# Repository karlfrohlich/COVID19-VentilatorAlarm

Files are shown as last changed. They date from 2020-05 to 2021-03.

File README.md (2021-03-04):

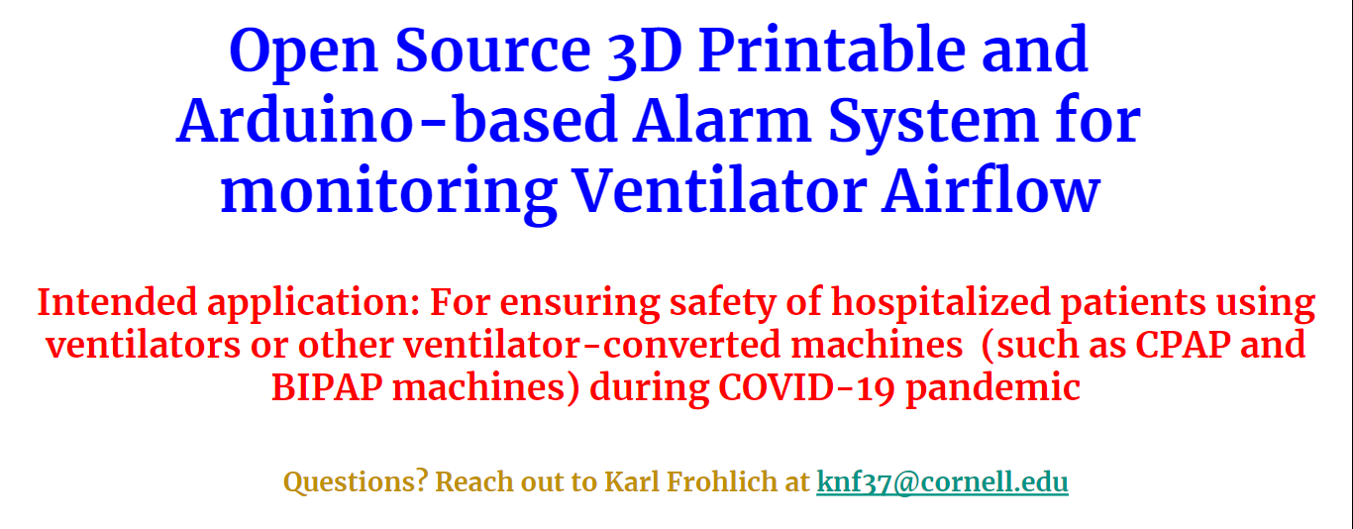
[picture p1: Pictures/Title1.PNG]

________________________________________________________________________________________________________________________________

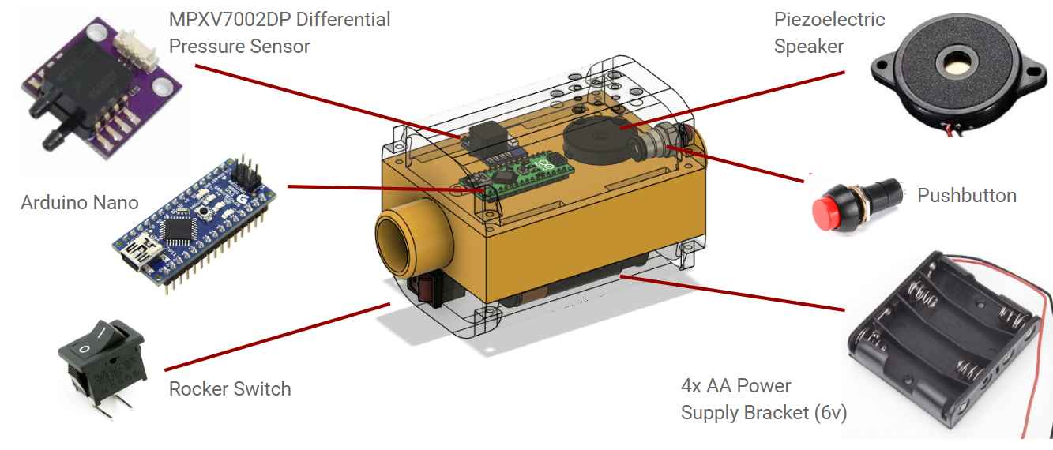
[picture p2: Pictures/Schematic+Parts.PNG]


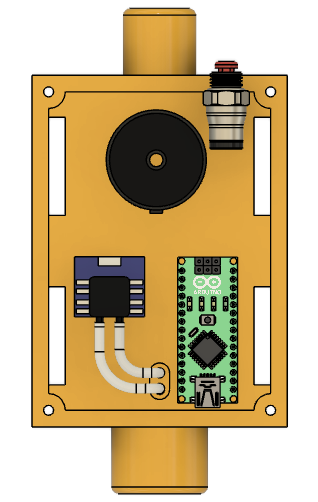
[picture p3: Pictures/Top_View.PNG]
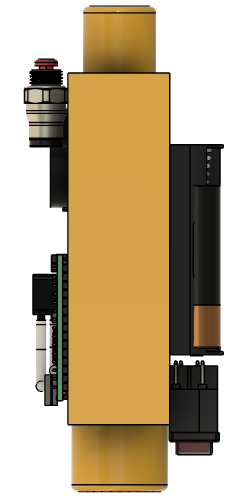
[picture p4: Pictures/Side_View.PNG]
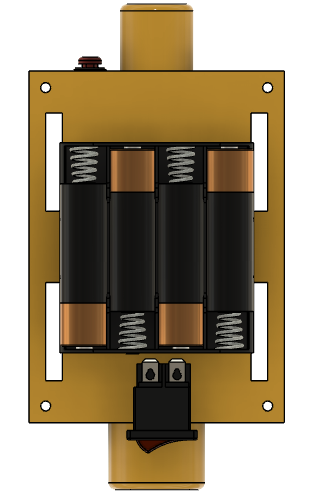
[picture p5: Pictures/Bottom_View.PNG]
 

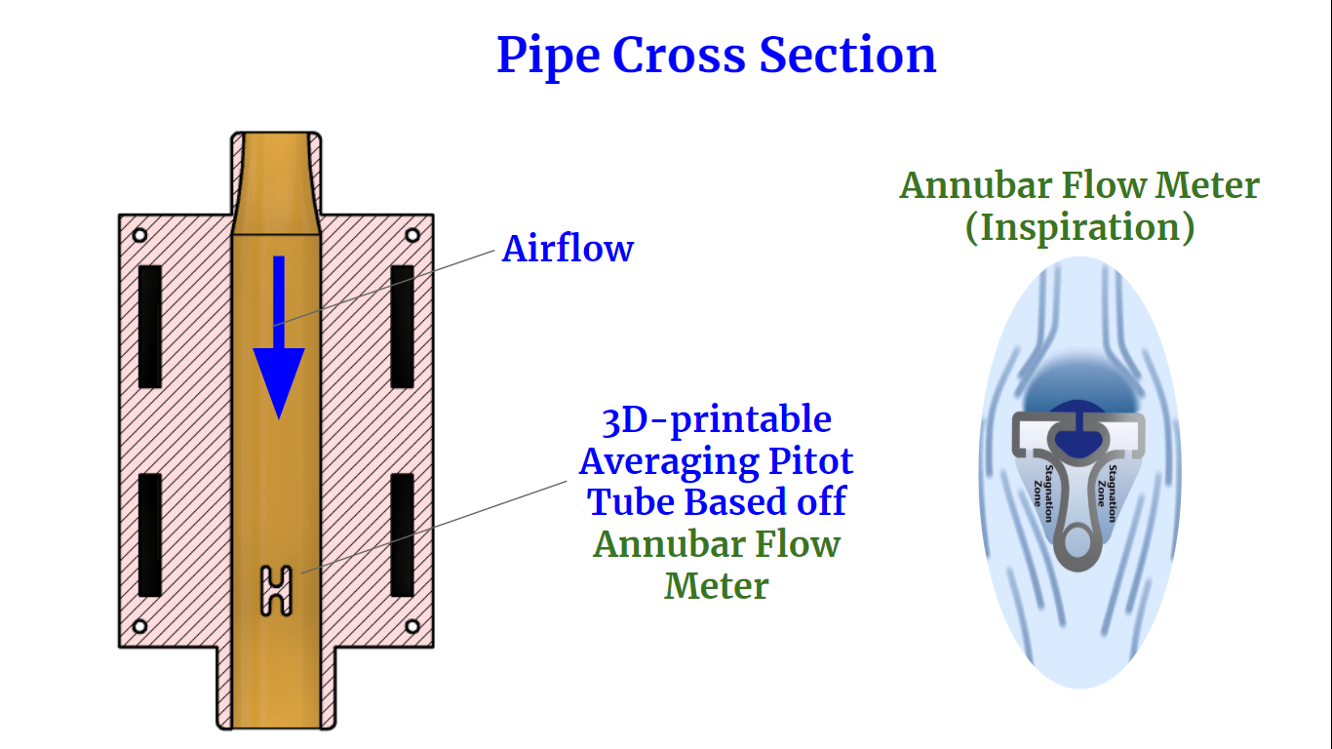
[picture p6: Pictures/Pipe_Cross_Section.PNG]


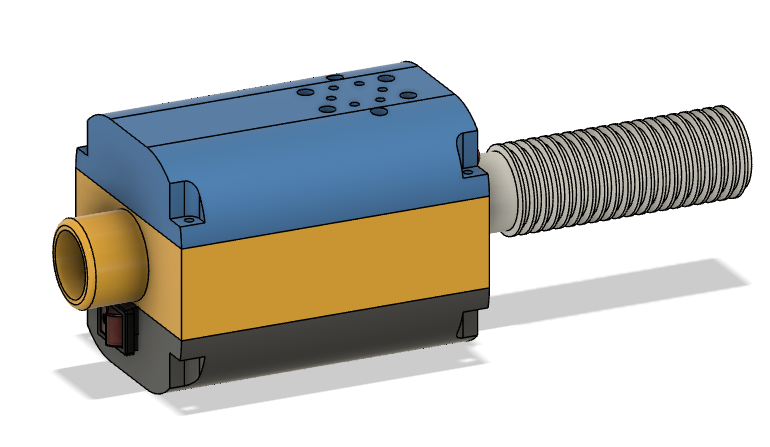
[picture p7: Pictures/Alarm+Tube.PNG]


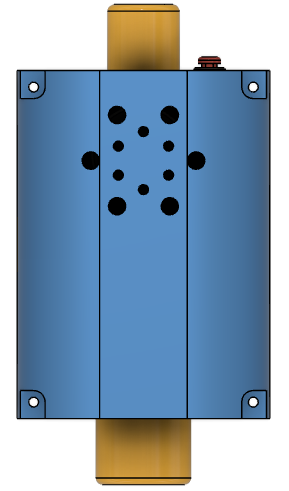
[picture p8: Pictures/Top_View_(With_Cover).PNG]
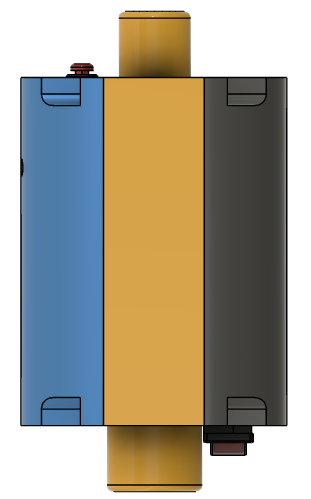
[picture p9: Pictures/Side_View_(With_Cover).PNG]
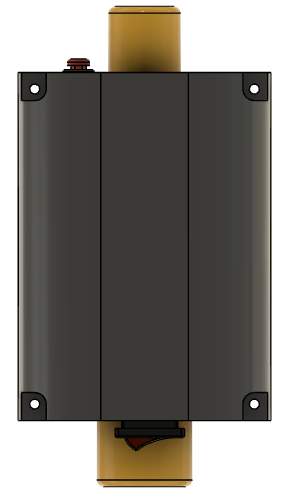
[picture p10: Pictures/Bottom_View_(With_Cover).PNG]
   

# Code Simulated Using Autodesk Tinkercad (See Code folder)
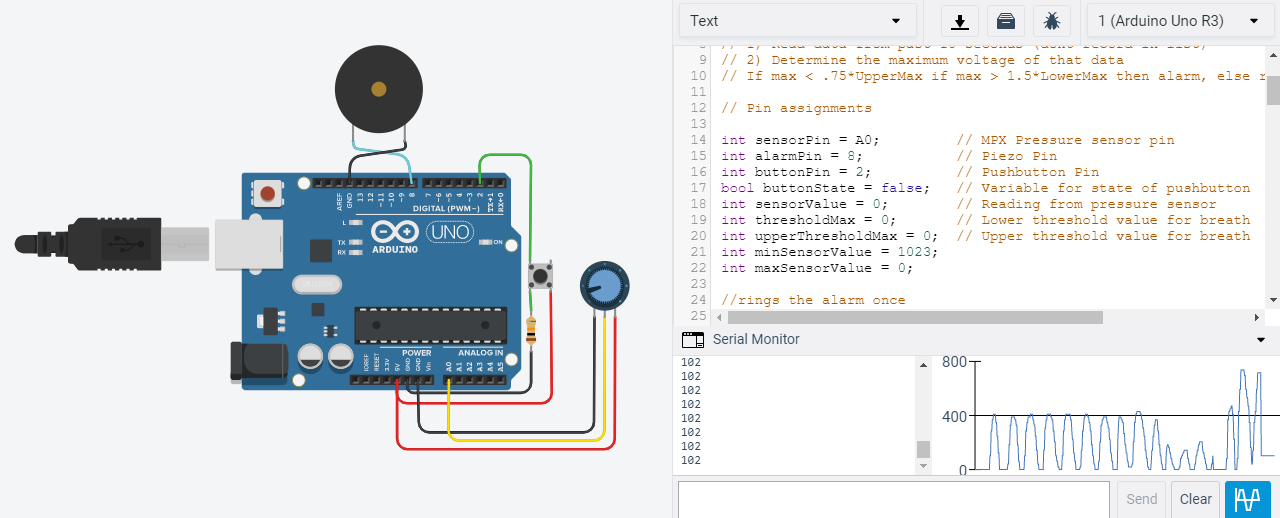
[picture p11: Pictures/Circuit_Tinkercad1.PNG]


## How to Make the Alarm System:
### 1) Purchase all electronic components listed in the Required_Parts Folder
### 2) Download .STL files from the 3D_Printed_Parts Folder
### 3) 3D Print the files (we recommend using PLA plastic at >50% infill)
### 4) Assemble the plastic and electric parts to specification as seen in the Pictures Folder
### 5) Download the code from the Arduino_Code Folder and upload it to the Arduino Board

### 6) Contact me at knf37@cornell.edu for any questions

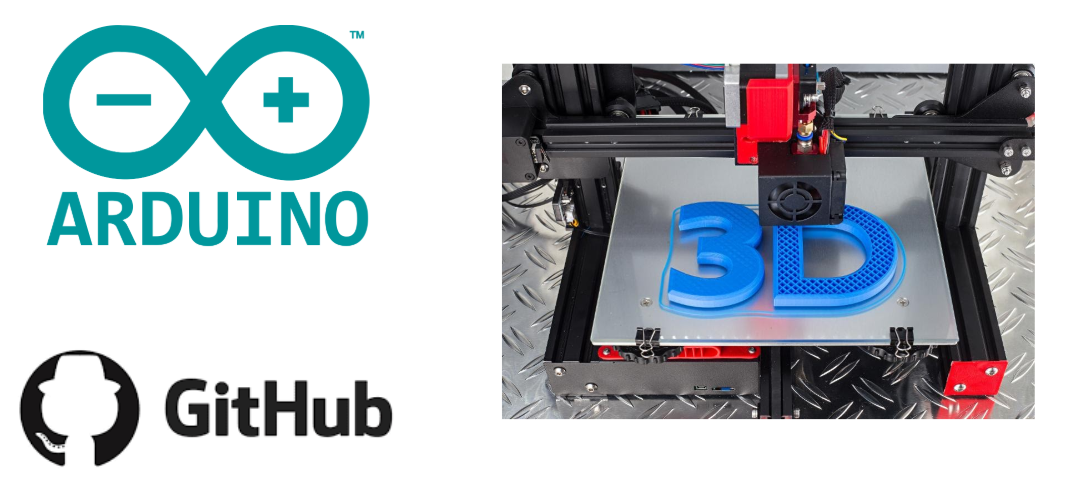
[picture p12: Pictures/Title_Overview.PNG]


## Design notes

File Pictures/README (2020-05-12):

Final Presentation File includes all slides presented on 5/12/2020 for for the Cornell Spring 2020 Class titled "Bioinstrumentation". Course code: BEE 4500

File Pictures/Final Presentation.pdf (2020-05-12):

# An Open Source 3D Printable and Arduino-based Alarm System for monitoring Ventilator Airflow

# Dr. Alex Maag’s Capstone Design Group:

# - Karl Frohlich

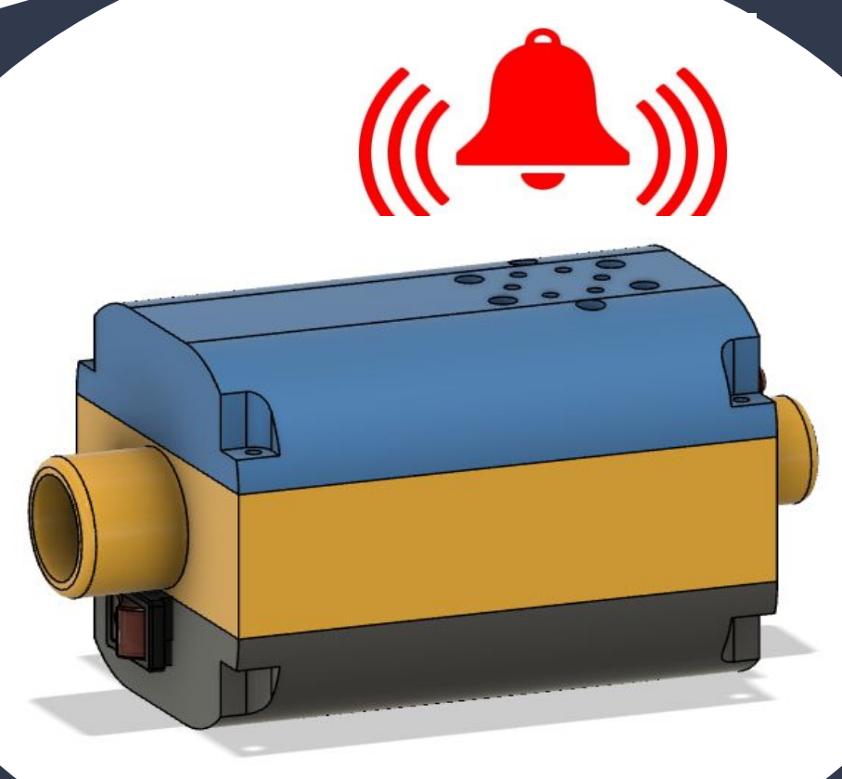
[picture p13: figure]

# - Ian McNitt

# - Noah Marinaro

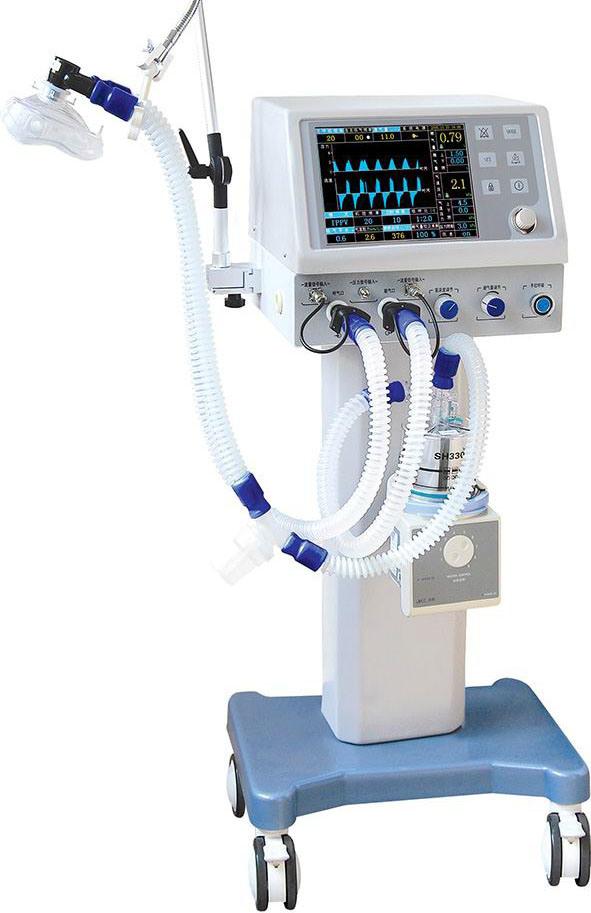
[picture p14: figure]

# Background

## Patient demand of medical equipment during the COVID-19 Pandemic has crippled the supply:

## - Limited to no access to available ventilators - Italy, Spain and NYC are experiencing drastic shortages along with rural hospitals - On March 22, the FDA fast tracked converting sleep apnea machines to ventilators to meet demand - CPAP - BIPAP

# Auburn’s RE-INVENT Project

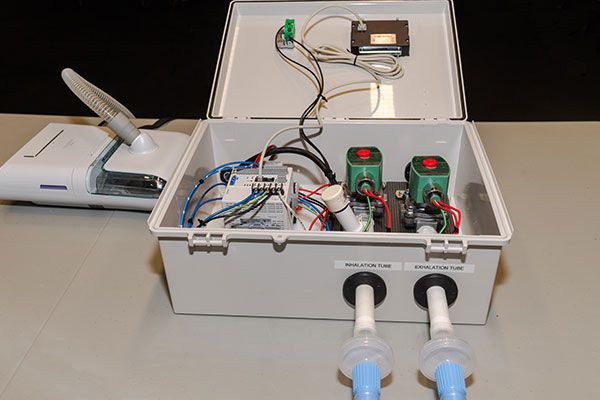
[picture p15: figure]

### Auburn University successfully re-purposed a standard CPAP machine into a functional emergency ventilator:

### - Cost approximately $700 worth of off-the-shelf components - Inspiration to expiration ratio: 1:3 - 3:1 - Breaths per minute: 10 - 30 BPM - Air pressure set: 5 - 25 cmH2O - Alarm senses deviations from patient parameters

# Problems:

## - Aggressive development

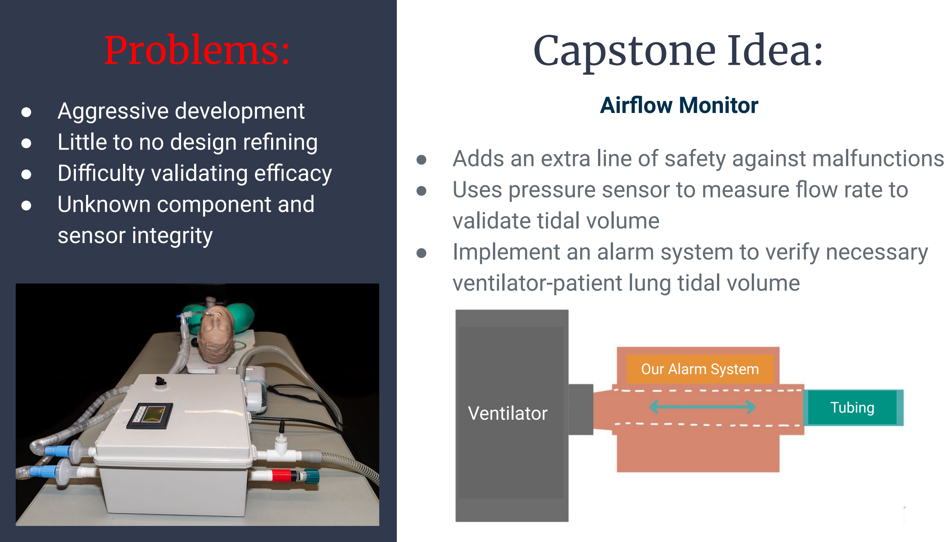
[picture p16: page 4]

## - Little to no design refining - Difficulty validating efficacy - Unknown component and sensor integrity

# Capstone Idea:

## Airflow Monitor

## - Adds an extra line of safety against malfunctions - Uses pressure sensor to measure flow rate to validate tidal volume - Implement an alarm system to verify necessary ventilator-patient lung tidal volume

### Ventilator

Our Alarm System

Tubing

# How Mechanical Ventilation Works

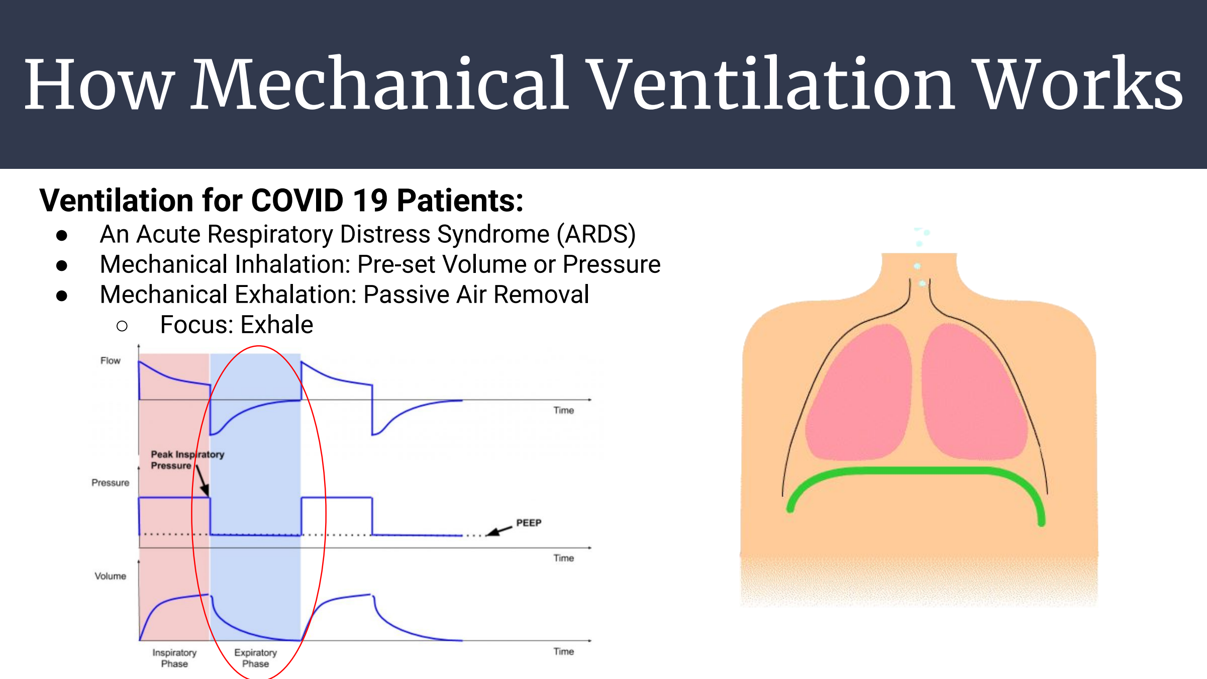
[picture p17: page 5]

# Ventilation for COVID 19 Patients:

## - An Acute Respiratory Distress Syndrome (ARDS) - Mechanical Inhalation: Pre-set Volume or Pressure - Mechanical Exhalation: Passive Air Removal - Focus: Exhale

# Ventilator Basics

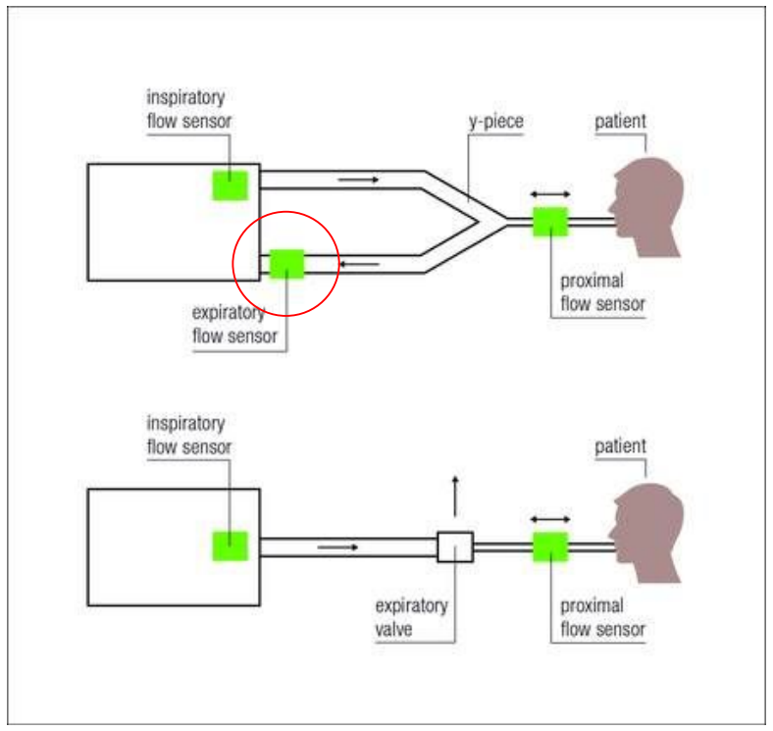
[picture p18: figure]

## 1. Tidal Volume a. The volume of air the lungs will receive b. Set by a medical professional c. What we will be measuring

## 2. Inspiratory Phase (‘Triggering’) a. Inside the ventilator

## 3. Expiratory Phase (‘Cycling’) a. Our emphasis b. Outside the ventilator c. Difficult to tamper with

# Using a Pitot Tube to Measure Flow Rate

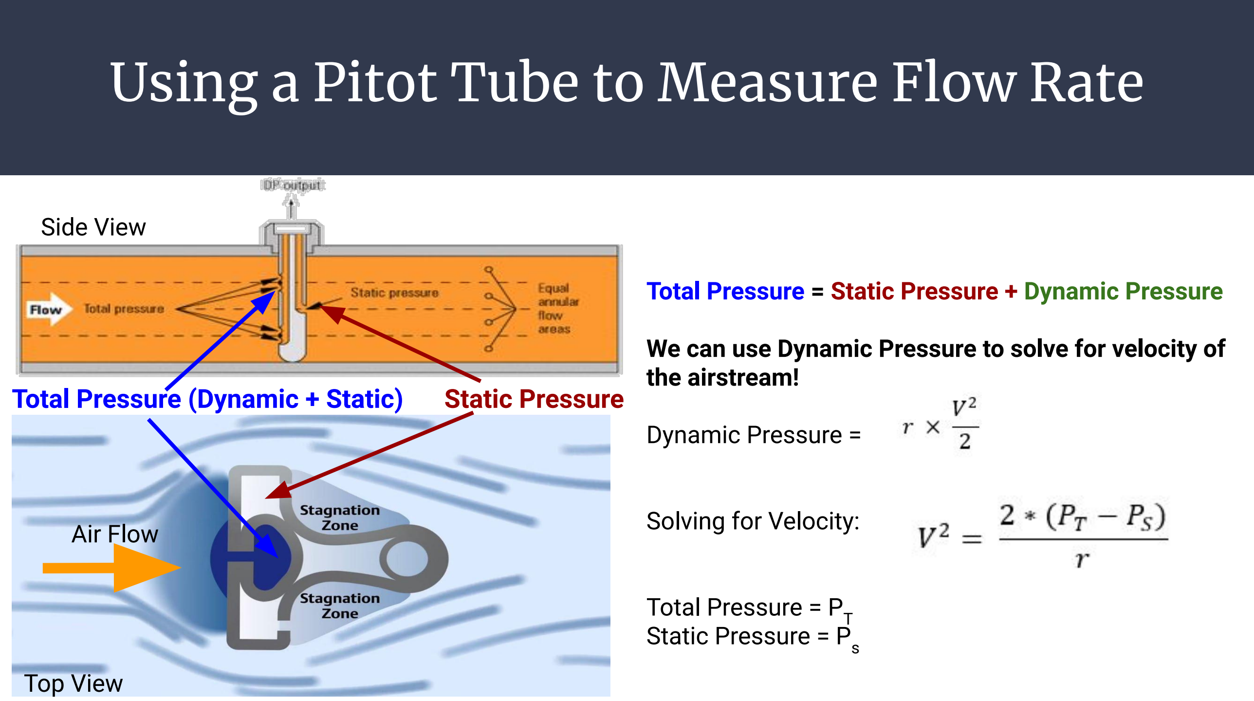
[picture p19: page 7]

## Total Pressure (Dynamic + Static) Static Pressure

### Total Pressure = Static Pressure + Dynamic Pressure

### We can use Dynamic Pressure to solve for velocity of the airstream!

### Dynamic Pressure =

### Solving for Velocity:

### Total Pressure = PT Static Pressure = P

s

### Air Flow

### Side View

### Top View

# An Open Source 3D Printable and Arduino-based Alarm System for monitoring Ventilator Airflow

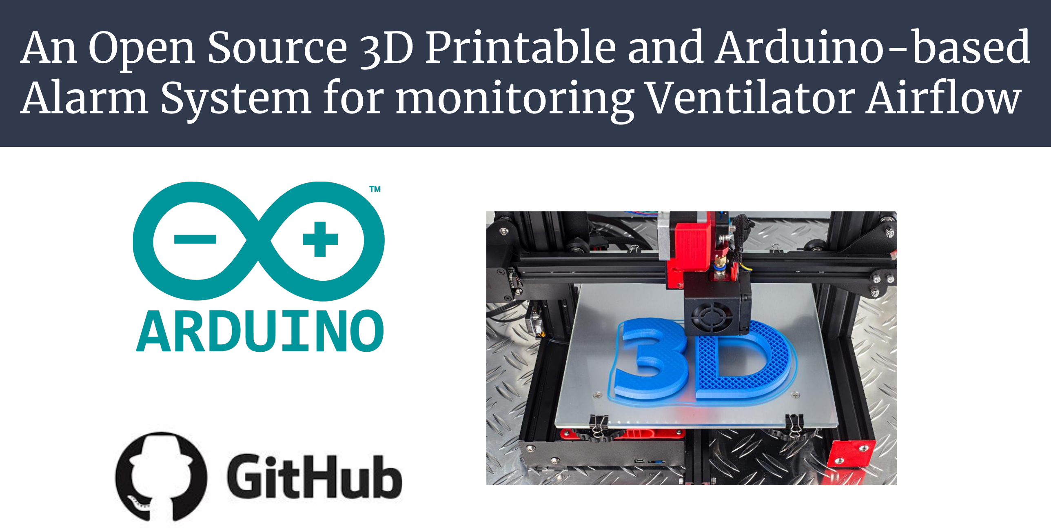
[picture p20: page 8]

# Hardware Overview

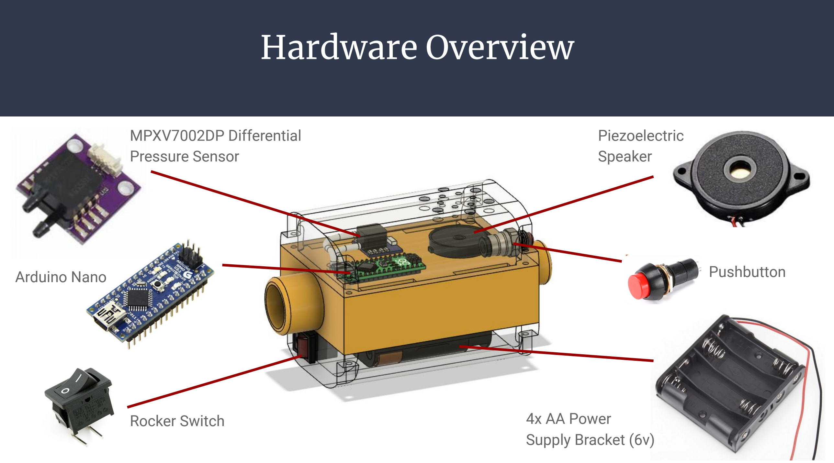
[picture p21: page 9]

### MPXV7002DP Differential Pressure Sensor

### 4x AA Power Supply Bracket (6v)

### Piezoelectric Speaker

### Pushbutton Arduino Nano

### Rocker Switch

# Parts Required

Picture | Part | Price (approx) as of May 2020
| | | Arduino Nano | $7

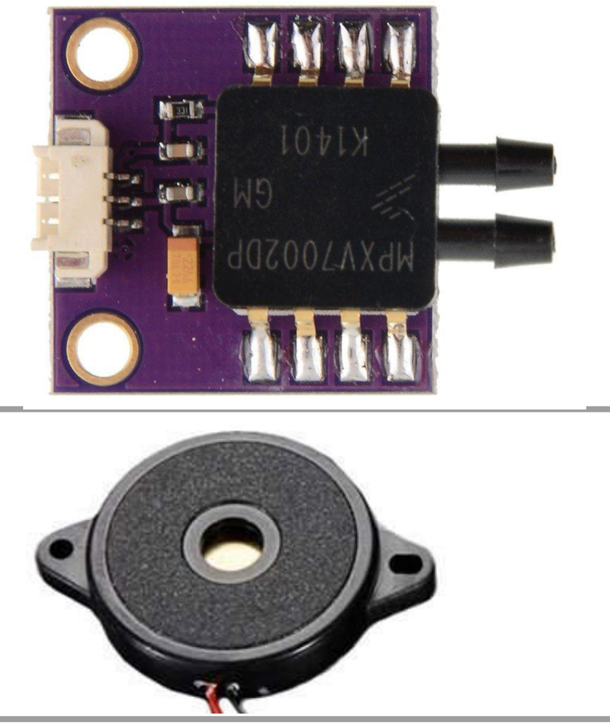
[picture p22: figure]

| | | MPXV7002DP Differential Pressure Sensor | $16
| | | Piezoelectric Speaker | $1
| | | | | 4x AA Power Supply (6V) + 4 AA Batteries | $5
| | | | | | | Pushbutton + Rocker Switch + Resistor + Wires + Screws + 3mm diameter rubber pipe
$11 | Total = $40/unit

# Procedure

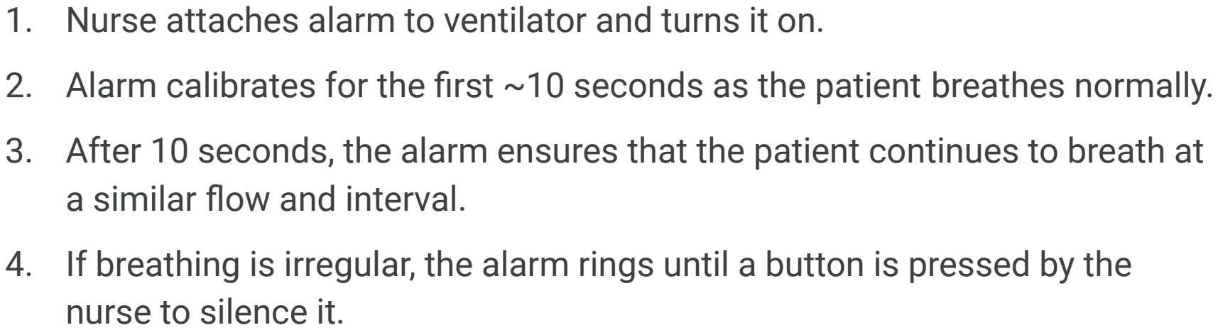
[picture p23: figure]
a similar flow and interval.; nurse to silence it.

1. Nurse attaches alarm to ventilator and turns it on.
2. Alarm calibrates for the first ~10 seconds as the patient breathes normally.

# 3. After 10 seconds, the alarm ensures that the patient continues to breath at

# 4. If breathing is irregular, the alarm rings until a button is pressed by the

# Software/Circuit Overview

# Modeled and Simulated using Autodesk Tinkercad!

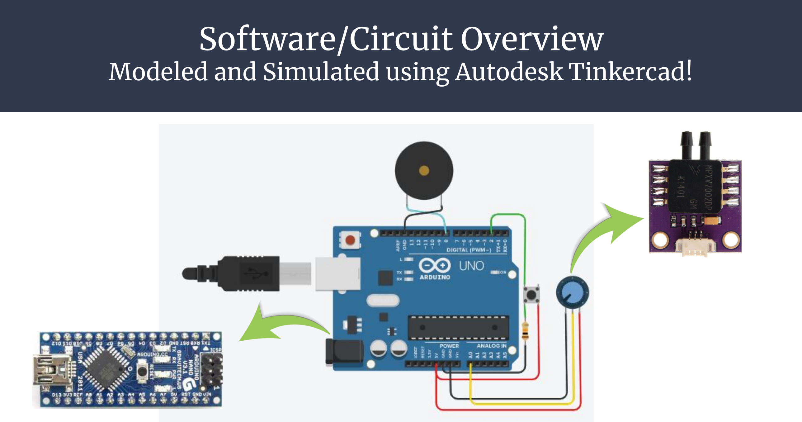
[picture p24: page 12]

# How do you build our Alarm System? Visit our Public Github Repository!

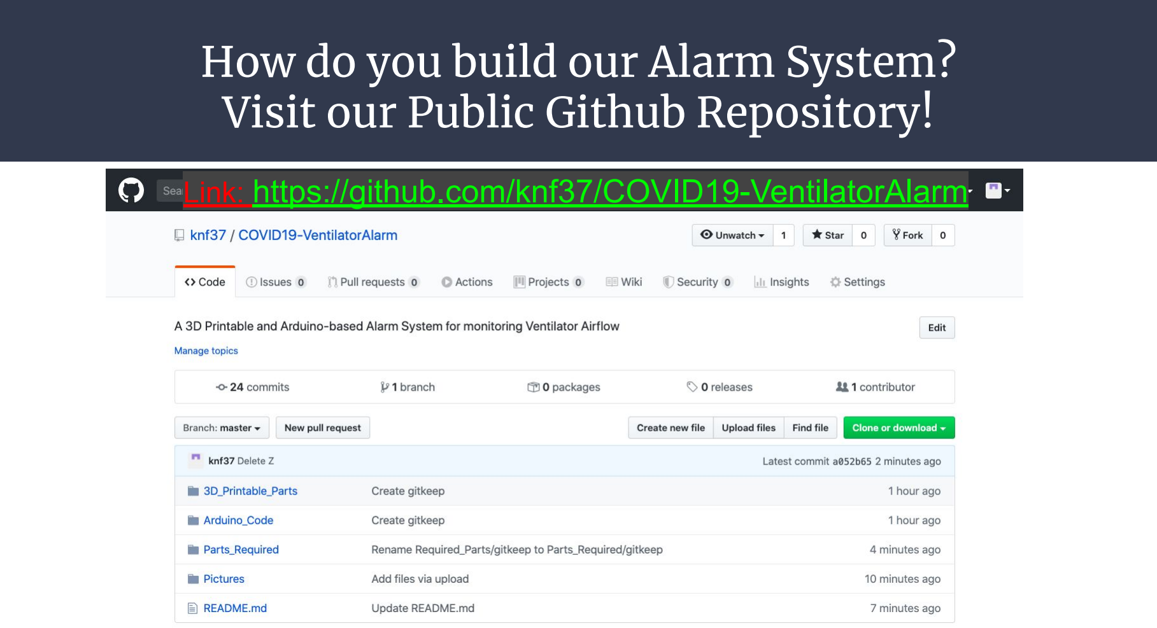
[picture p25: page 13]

# Link: https://github.com/knf37/COVID19-VentilatorAlarm

# Future Direction

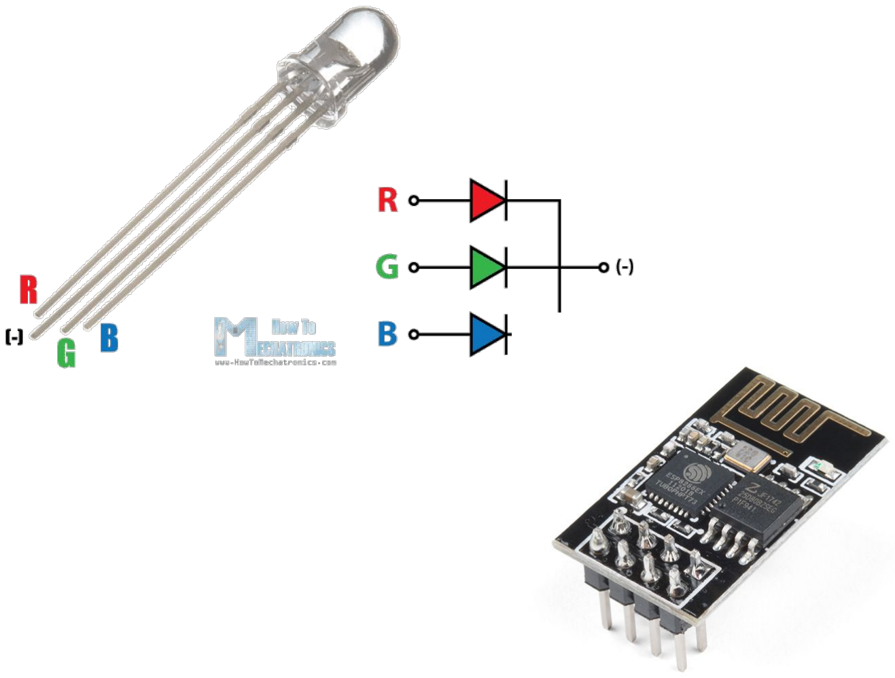
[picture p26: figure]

## - Improve alarm system with LED light - Green = Normal - Yellow = Warning - Red = Needs Attention

## - Transmitter (ESP8266) - Inexpensive ($7) - 24 / 7 monitor capability - Enhanced safety

# Additional Components

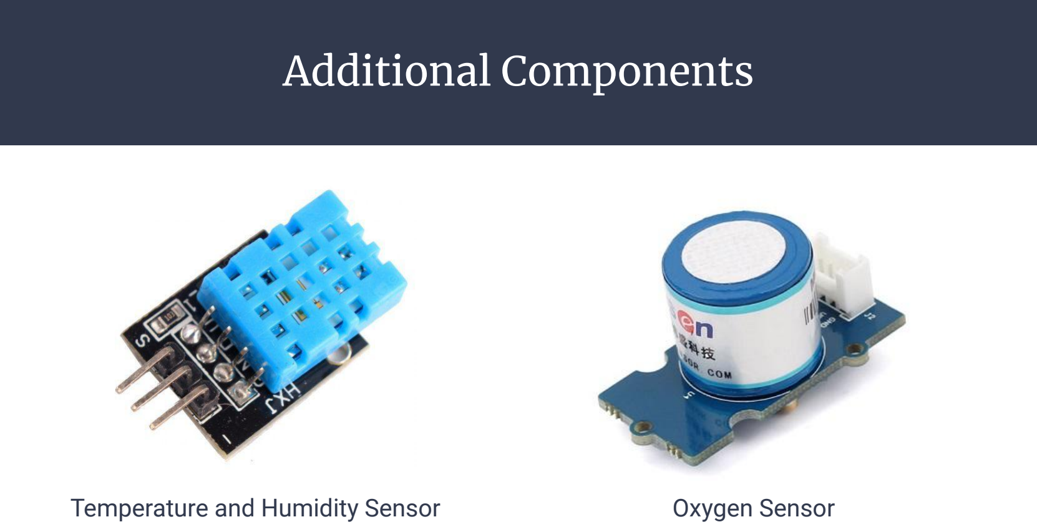
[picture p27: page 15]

Temperature and Humidity Sensor | Oxygen Sensor

# Future Aim

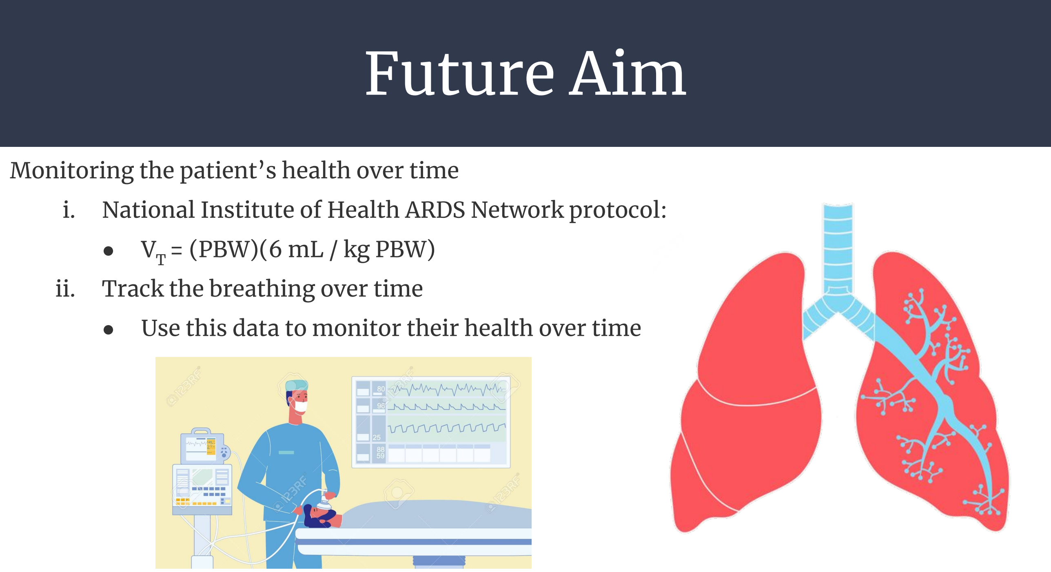
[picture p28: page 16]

# Monitoring the patient’s health over time i. National Institute of Health ARDS Network protocol: - VT = (PBW)(6 mL / kg PBW) ii. Track the breathing over time - Use this data to monitor their health over time

# References

Average Height By State 2020. (2020, April 6). Retrieved May 8, 2020, from https://worldpopulationreview.com/states/average-height-by-state/

Benson, T. Pitot Tube. Retrieved May 8, 2020, from https://www.grc.nasa.gov/WWW/k-12/VirtualAero/BottleRocket/airplane/pitot.html

Burch, T., & Zabala, M. THE AUBURN RE-INVENT PROJECT. Retrieved May 7, 2020, from http://eng.auburn.edu/reinvent

Khoury-Folkens, C. VENTILATOR SOS. Retrieved May 7, 2020, from https://www.ventilatorsos.com/

Mechanical Ventilation. (2016, July). Retrieved May 8, 2020, from https://craighospital.org/resources/mechanical-ventilation

Miller, S., & Wysocki, M. Tidal volumes for ventilated patients should be determined at the endotracheal tube. Retrieved May 7, 2020, from https://www.hamilton-medical.com/dam/jcr:abe1ac16-8732-4bcd-a209-7c5faa076aa8/flow-sns-position_whitepaper-en-689217.00.pdf

Silva, P. L., & Rocco, P. (2018). The basics of respiratory mechanics: ventilator-derived parameters. Annals of translational medicine, 6(19), 376. https://doi.org/10.21037/atm.2018.06.06

Pressure Measuring - MIT E-Vent: MIT Emergency Ventilator. (2020, April 4). Retrieved May 8, 2020, from https://e-vent.mit.edu/controls/pressure-measuring/

# Questions?

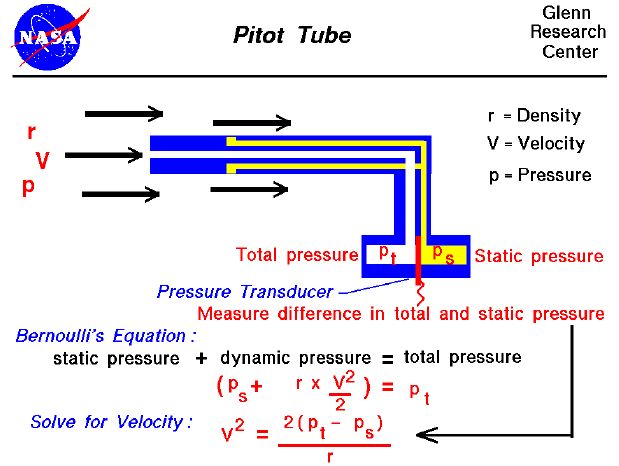
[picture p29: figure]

## Determining the Tidal Volume:

## Q = Flow Rate (m³

/s)

## V = Volume (m³

)

## A = Area (m²

)

## d = distance (m) v = Velocity (m/s) t = Time (s)

## Q = V / t = A*d / t = A*v

## Tidal Volume (VT

) = Q*t

# Measuring Additional Parameters

## - Positive End Expiratory Pressure (PEEP) - Low PEEP: 3 - 5 cmH2O - High PEEP: 12+ cmH2O

## - Peak Inspiratory Pressure (PIP) - Low PIP < 30 cm H2O - High PIP > 40 cm H2O

## - Driving Pressure: PIP - PEEP < 15

# Potential Pressure Readings:

## - Target PEEP: 15 cmH2O - Target PIP: 30 cmH2O - With an I/E ratio of 2:1 and target PEEP: - Male = 424 mL / Female = 317 mL

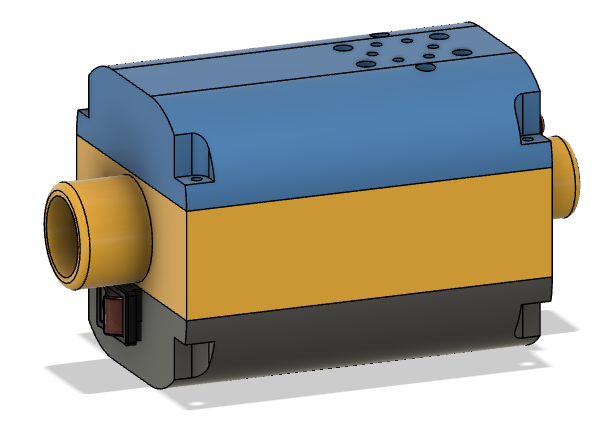
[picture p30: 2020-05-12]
Pictures/Schematic.PNG

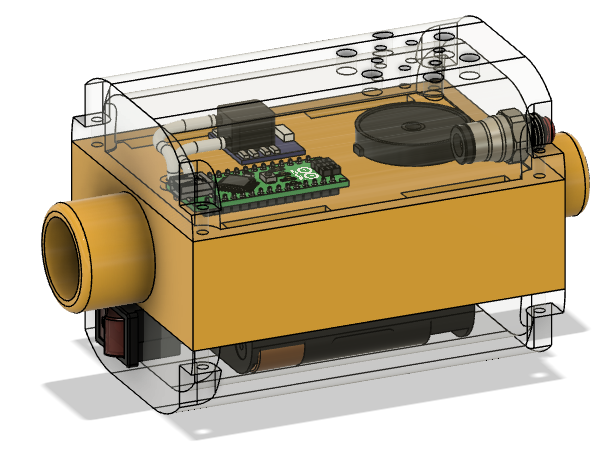
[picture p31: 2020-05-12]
Pictures/Skeleton.PNG

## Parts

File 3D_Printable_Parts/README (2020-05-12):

See full 3d model for the original Fusion 360 file

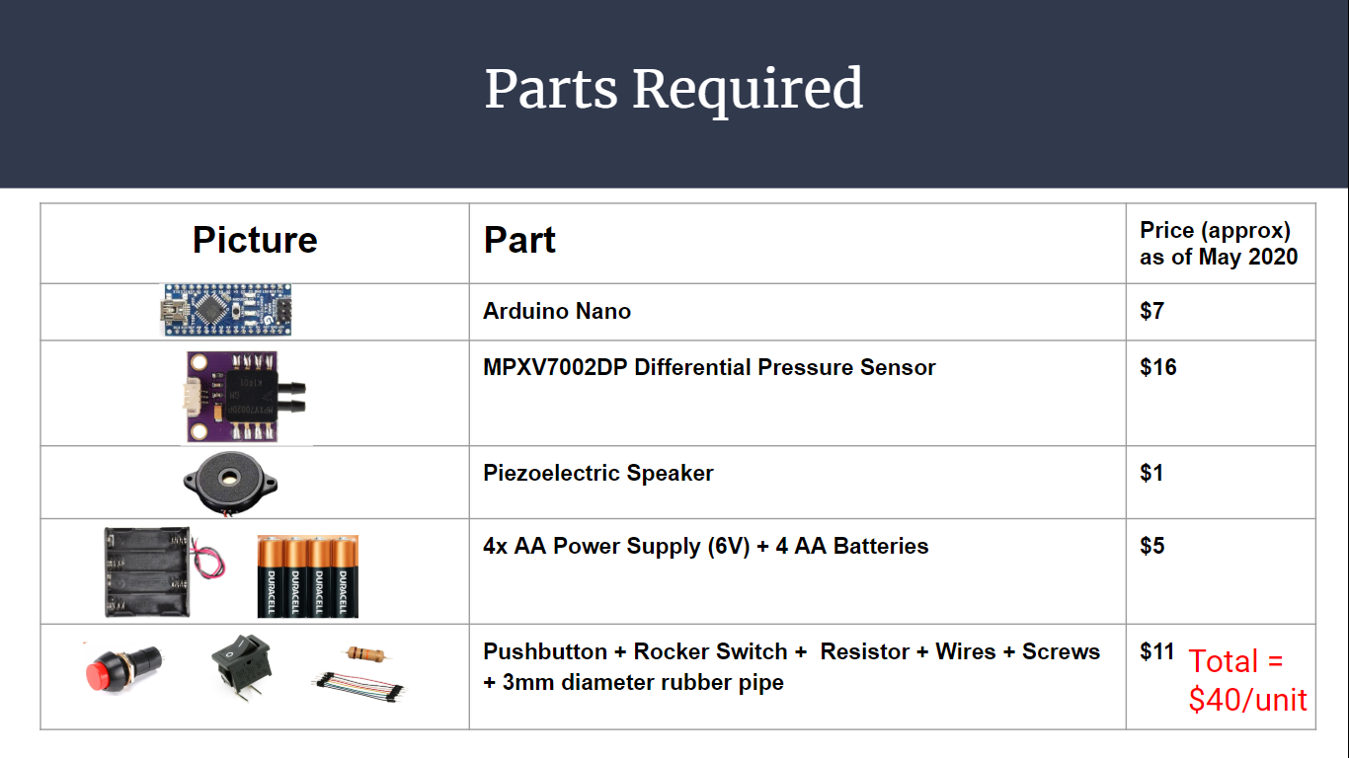
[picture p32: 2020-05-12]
Required_Parts/Parts_Required.PNG

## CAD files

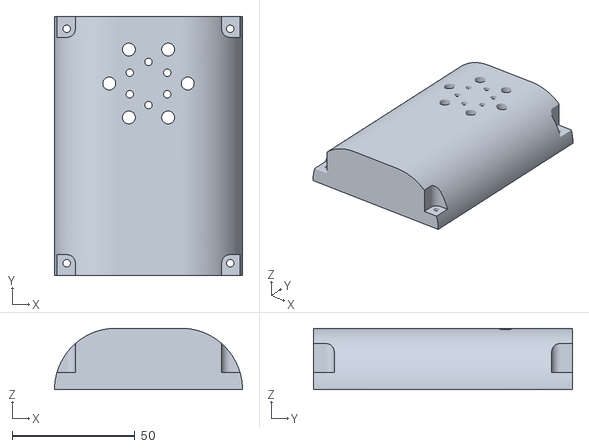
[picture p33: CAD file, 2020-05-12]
3D_Printable_Parts/Top Cover.stl
76.5 x 105.4 x 25.0

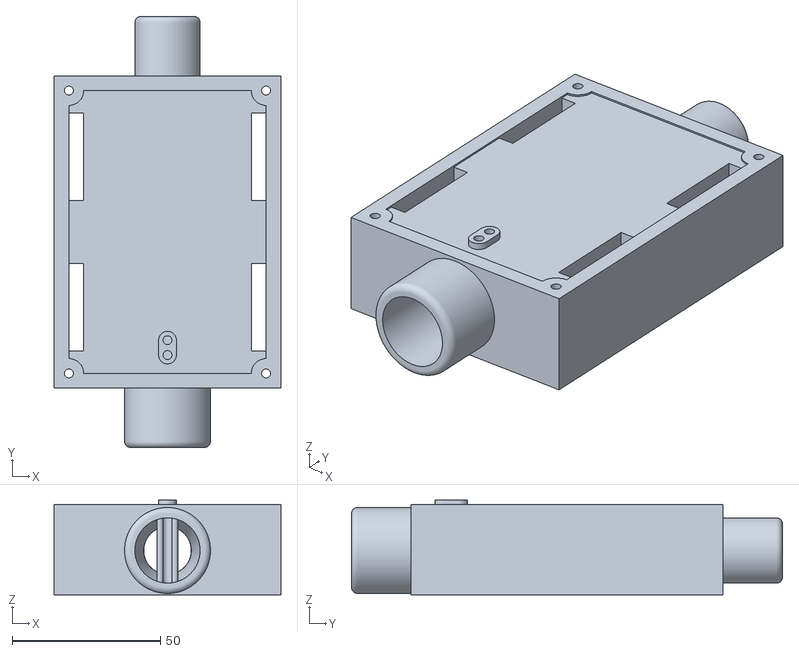
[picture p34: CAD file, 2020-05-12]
3D_Printable_Parts/Middle.stl
76.5 x 145.4 x 32.0

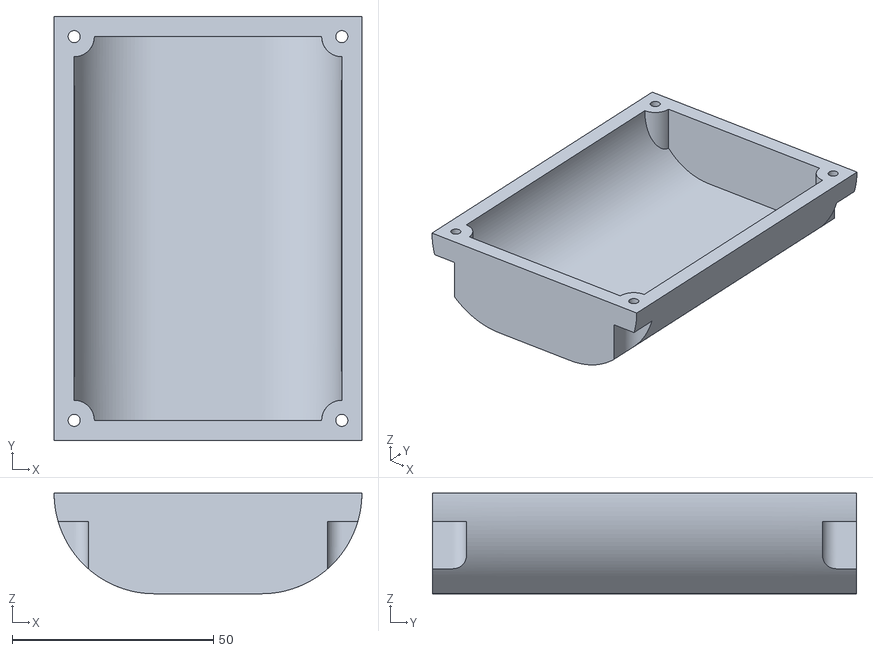
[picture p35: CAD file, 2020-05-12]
3D_Printable_Parts/Bot Cover.stl
76.5 x 105.4 x 25.0

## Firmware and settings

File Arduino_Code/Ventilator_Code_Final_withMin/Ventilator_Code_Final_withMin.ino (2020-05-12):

// void calibrate(){
// 1) Create array of past 10 seconds of data
// 2) Determine the maximum voltage of that list
// 3) Set the threshold voltage to .75 * Max
// 4) Find the first instance of voltage data which crosses the threshold
// 5) Find the next instance of voltage data which goes below the threshold
// 6) Repeat previous 2 steps until all peaks are isolated
// 7) Calculate the average distance between those peaks
//
// void moniter(){
// Repeat steps 4-7
// Ensure that healthy breaths per second are occuring


// void calibrate(){
// 1) Read data from past 8 seconds
// 2) Determine the maximum and minimum voltage of that data
// 3) Set the threshold voltage to .75 * Max and .25 * (Min+1) (to avoid multiplying by 0)

// void loop(){
// Ensure that healthy breaths are occuring
// 1) Read data from past 10 seconds (dont record in list)
// 2) Determine the maximum voltage of that data
// If max < .75*UpperMax if max > 1.5*LowerMax then alarm, else repeat

/*
  Attach the center pin of a the MPX pressure sensor to pin
  A0, and the outside pins to +5V and ground.
*/

// Pin assignments

int sensorPin = A0;         // MPX Pressure sensor pin
int alarmPin = 8;			      // Piezo Pin
int buttonPin = 2;			    // Pushbutton Pin
bool buttonState = false;   // Variable for state of pushbutton
int sensorValue = 0;		    // Reading from pressure sensor
int thresholdMax = 0;		    // Lower threshold value for breath 
int upperThresholdMax = 0;	// Upper threshold value for breath
int counter = 10;           // Currently unimplimented but used to increase the silence delay after pushing the button
int minSensorValue = 1023;
int maxSensorValue = 0;

//rings the alarm once
void alarmRing() {
  tone(alarmPin, 500);
  delay(500);
  noTone(alarmPin);
  delay(500);
}



void readAndRecordMax(double duration) {
  minSensorValue = 1023;
  maxSensorValue = 0;
  long startTime = millis();
  while (millis() - startTime < (duration * 1000)) {
    // read the input on analog pin 0:
    sensorValue = analogRead(sensorPin);
    if (sensorValue < minSensorValue)
      minSensorValue = sensorValue;
    if (sensorValue > maxSensorValue)
      maxSensorValue = sensorValue;

    Serial.println(sensorValue);

    //    //print the data for debugging purposes
    //    Serial.print("Val = ");
    //    Serial.print(sensorValue);
    //    Serial.print("\tMin = ");
    //    Serial.print(minSensorValue);
    //    Serial.print("\tMax = ");
    //    Serial.println(maxSensorValue);
    delay(50);
  }
}

/**
  1) Read data from past 10 seconds (dont record in list)
  2) Determine the maximum voltage of that data
  3) Set the threshold voltage to .75 * Max
*/
void calibrate() {
  // 1) Read data from past 10 seconds (dont record in list)
  // 2) Determine the maximum voltage of that data
  readAndRecordMax(8);

  // 3) Set the threshold voltage to .75 * Max
  thresholdMax = 0.75 * maxSensorValue;
  upperThresholdMax = 1.5 * maxSensorValue;
}

//update the button state
void updateButtonState() {

  //  if (counter == 0) {
  //    //reset counter
  //    counter = 10;
  //    buttonState = false;
  //  } else {
  //    counter--;
  //  }
  if (digitalRead(buttonPin) == HIGH) {
    buttonState = true;
    counter = 10;
  }
}

void setup() {
  pinMode(sensorPin, INPUT);
  pinMode(buttonPin, INPUT);
  Serial.begin(9600);
  Serial.println("Begin Calibration");
  calibrate();
  Serial.println("Finish Calibration");
}

/**
  1) Read data from past 10 seconds (dont record in list)
  2) Determine the maximum voltage of that data
  3) If max = .75* Max then alarm... else repeat
*/
void loop() {
  Serial.println("Begin Monitering Block");
  // 1) Read data from past 10 seconds (dont record in list)
  // 2) Determine the maximum voltage of that data
  readAndRecordMax(4);

  Serial.print("Val = ");
  Serial.print(sensorValue);
  Serial.print("\tMin = ");
  Serial.print(minSensorValue);
  Serial.print("\tMax = ");
  Serial.println(maxSensorValue);
  Serial.print("Threshold = ");
  Serial.println(thresholdMax);
  Serial.print("ButtonState = ");
  Serial.println(buttonState);

  // 3) If max = .75* Max then alarm... else repeat
  if (maxSensorValue <= thresholdMax || maxSensorValue >= upperThresholdMax) {
    while (buttonState == false) {
      alarmRing();
      updateButtonState();
    }
    buttonState = false;
  }
}
